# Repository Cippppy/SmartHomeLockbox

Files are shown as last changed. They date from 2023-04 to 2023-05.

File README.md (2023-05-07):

# Smart Home Lockbox
The Smart Home Lockbox is a project created by Christian Cipolletta and Matt Gerace for their final in Intro To Embedded Systems. It is a tool that will allow people to lock their important items. It utilizes Ultrasonic, temperature, CO2, humidity, pressure, and vibration sensors to be aware of external stimuli. The microcontroller, the MSP430FR2355, takes in those inputs and alerts the user to danger using buzzers, LEDs, and an internet webpage. A servo also locks the box if someone is detected.

## Power Supply
* Barrel Jack [For AC/DC Wall Plug]
* 2x 20mm Coin Cell Batteries + Holders
* 2x Linear Regulators, 1 for 5V, 1 for 3.3V

## Sensors
* BME280 Temperature, Humidity, Pressure Sensor Breakout Board [I2C]
* MQ-9B (Sen-17050) CO2 Sensor [Analog]
* MSP430FR2355 On Board Temperature Sensor [Analog]
* HC-SR04 Ultrasonic Sensor [Digital]
* MPU6050 Accelerometer and Gyroscope [I2C]

## Output Peripherals
* Red LED
* Blue LED
* Active Buzzer
* ESP01 Wifi Module [[ThingSpeak]](https://thingspeak.com/channels/2104523)
* Servo

## Where is the project at? (5/7/2023)
The onboard temperature sensor and ultrasonic sensors are confirmed to be working. The CO2 gives an ouput, but we do not know if it is correct. The batteries are not strong enough to run the circuit, so it is wall power right now. The I2C code doesn't work so the BME280 and MPU6050 aren't working now either. The servos, LEDs, buzzers, and ESP01 all work. The 3D printed box that will be the actual one that locks was successfully printed and locked by the servo. However, it was unable to be covered because it is too small to fit the full PCB at this time. You can read more on our [project slides](https://docs.google.com/presentation/d/1oNxZCWa-71zp4ZQAXbW0OE4L5BJcd05L6jm5VQH0Wrw/edit?usp=sharing) or our [project report](https://docs.google.com/document/d/1pnApUV6Cqu8zDdYJzm2F5OI0f5RzCBrWJ35Rd4LK8bY/edit?usp=sharing).

## Future Work
The next steps to take to make the project a full success start with remaking the PCB. First, the ESP01 needs to switch its trace. Second, the servo header needs to be retraced as well. Last, there needs to be a new battery choosen to the power the device. On the software side, the main fix is making sure the I2C connections are fixed. Once that is fixed, to make this device low-power it would be a benefit to make the code interrupt based instead of the current polling based system. The final thing to fix would be to make the lock box big enough to encase the PCB and all parts while still being able to be locked and to store items.

## Project Video
https://user-images.githubusercontent.com/98924381/235829279-1a4e9000-3827-43de-8596-dcd38e9c36f0.mp4

# Appendix
## Resources & Datasheets
* BME280 [Datasheet](https://cdn-learn.adafruit.com/downloads/pdf/adafruit-bme280-humidity-barometric-pressure-temperature-sensor-breakout.pdf), [Arduino Github](https://github.com/adafruit/Adafruit_BME280_Library)
* MPU6050 [Datasheet](https://www.haoyuelectronics.com/Attachment/GY-521/mpu6050.pdf)
* Ultrasonic [Datasheet](https://cdn.sparkfun.com/datasheets/Sensors/Proximity/HCSR04.pdf)
* MQ-9B [Datasheet](https://cdn.sparkfun.com/assets/d/f/5/e/2/MQ-9B_Ver1.4__-_Manual.pdf), [Wiring Example](http://wiring.org.co/learning/basics/airqualitymq135.html)
* Servo [Datasheet](http://www.ee.ic.ac.uk/pcheung/teaching/DE1_EE/stores/sg90_datasheet.pdf)
* ESP01 [Datasheet](https://www.universal-solder.ca/downloads/esp8266_series_modules_user_manual_en.pdf)
* Updating 3D Model of the Lockbox [OnShape](https://cad.onshape.com/documents/b93b4b42872b4098d45294de/w/dbbdbcc2a9ef1ffa882faf1d/e/f71d34ea460787590961a1fb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)

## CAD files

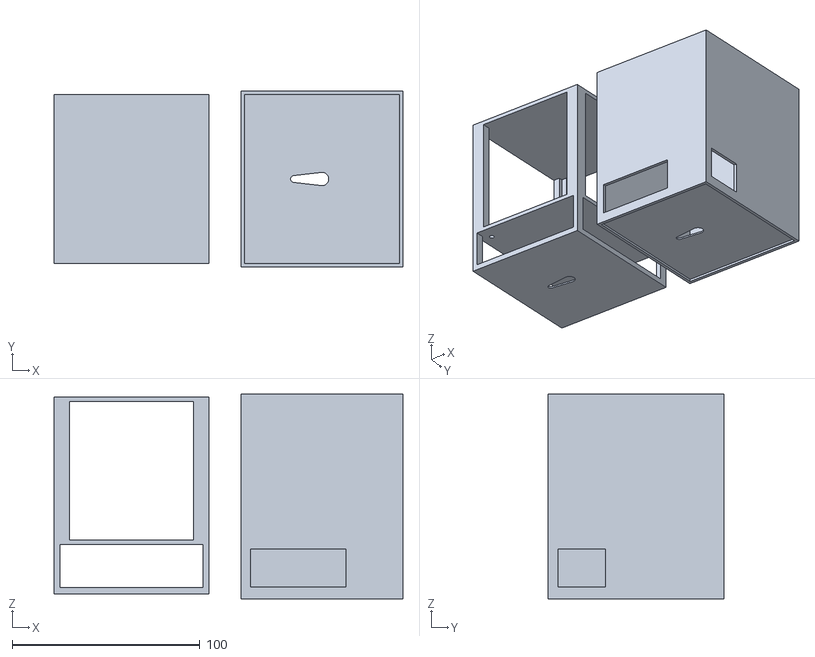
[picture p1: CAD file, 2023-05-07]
Lockbox_Model.stl
186.1 x 94.0 x 109.2

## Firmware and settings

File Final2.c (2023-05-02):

#include <msp430.h>
#include <stdint.h>
#include <stdbool.h>
#include "Drivers/GPIO_Driver.h"
#include "Drivers/FR2355_UART_Driver.h"
#include <Drivers/Adafruit_BME280.h>

/**
 * Final2.c
 */

// Variable Instantiation
char Vibration_Data_In;
float Temperature_Data_In;
float Humidity_Data_In;
float Pressure_Data_In;
volatile float CO2_Reading;
unsigned int position;

//on board temperature definitions
volatile float IntDegF;
#define CALADC_15V_30C  *((unsigned int *)0x1A1A)
#define CALADC_15V_85C  *((unsigned int *)0x1A1C)

//ADC mode definitions
#define CO2 1
#define OBTEMP 0
volatile unsigned char modeADC = 0x00;

// Text that prints to terminal if distance < 15
char alertText[] = {'D','A','N','G','E','R', ' ','N','E','A','R'};

// Text that prints to terminal when uart connects
char connectedText[] = {'S','u','c','c','e','s','s','f','u','l','l','y',' ','C','o','n','n','e','c','t','e','d'};

volatile unsigned long distance = 20;    // Holds distance calculated by ultrasonic sensor
volatile unsigned int pulseCount = 0;   // Holds count used to calculate distance

// Peripheral Instantiation
void Init_HCSR04();
void Init_Buzzer();
void Init_Servo();
void Init_LED();
void Init_WIFI();
void Init_TEMP();
void Init_CO2();
void Init_UART_Pins();
void Run_Ultrasonic();
// Method Instantiation
void readOBTemp();
void Init_ADC();
void readCO2();
void updateThingSpeak();
//void Run_Temp();
void Ultrasonic_Wait(unsigned int timeToWait);
void setServo(unsigned int angle);


void main(void)
{
    WDTCTL = WDTPW | WDTHOLD;                 // Stop WDT
    distance = 20;
    Init_HCSR04();
    Init_Buzzer();
    Init_Servo();
    Init_LED();
    Init_WIFI();
    Init_TEMP();
    Init_CO2();
    Init_ADC();
    Init_UART_Pins();

    // Disable the GPIO power-on default high-impedance mode to activate
    // previously configured port settings
    PM5CTL0 &= ~LOCKLPM5;

    __bis_SR_register(LPM0_bits + LPM3_bits + GIE); // Enter LPM0 and LPM3
    __enable_interrupt();   // Enables interrupts
    __no_operation();       // For debugger

    while(1)
    {
        Run_Ultrasonic();
        readOBTemp();
        while((ADCIFG & ADCIFG)==0);
        readCO2();
//        Run_Temp();
//        Temperature_Data_In = readTemperature();
//        Humidity_Data_In = readHumidity();
//        Pressure_Data_In = readPressure();
        if(distance < 15) { // If distance is less than 15 (maybe cm?)
            setServo(180);
            gpioWrite(3,2,1);   // Turn on Red LED
            gpioWrite(3,3,1);   // Turn on Blue LED
            gpioWrite(3,7,1);   // Turn on Buzzer
        }
        else {  // If distance is further than 15
            setServo(0);
            gpioWrite(3,2,0);   // Turn off Red LED
            gpioWrite(3,3,0);   // Turn off Blue LED
            gpioWrite(3,7,0);   // Turn off buzzer
        }
        updateThingSpeak();
        Ultrasonic_Wait(65000); // Wait some time (Maybe 65000 ms)
    }
}


/**
 * Peripheral Setups
 */

// Sets up ADC for On-Board Temp sensor and CO2 sensor
void Init_ADC()
{
    ADCCTL0 |= ADCSHT_8 | ADCON;                                  // ADC ON,temperature sample period>30us
    ADCCTL1 |= ADCSHP;                                            // s/w trig, single ch/conv, MODOSC
    ADCCTL2 &= ~ADCRES;                                           // clear ADCRES in ADCCTL
    ADCCTL2 |= ADCRES_2;                                          // 12-bit conversion results
    ADCMCTL0 |= ADCSREF_1 | ADCINCH_12;                           // ADC input ch A12 => temp sense
    ADCIE |=ADCIE0;                                               // Enable the Interrupt request for a completed ADC_B conversion
    modeADC = OBTEMP;

    PMMCTL0_H = PMMPW_H;                                          // Unlock the PMM registers
    PMMCTL2 |= INTREFEN | TSENSOREN;                              // Enable internal reference and temperature sensor
    __delay_cycles(400);                                          // Delay for reference settling
}

// Setting up pins for Computer terminal connection
void Init_UART_Pins()
{
    P4DIR = 0xFF; P2DIR = 0xFF;
    P4REN = 0xFF; P2REN = 0xFF;
    P4OUT = 0x00; P2OUT = 0x00;
    // Configure UART pins
    P4SEL0 |= BIT2 | BIT3;                    // set 2-UART pin as second function
}


// Setup Ultrasonic sensor to Pins 5.1 and 5.0 and Timer B2
void Init_HCSR04()
{
    gpioInit(5,1,1); // Set Pin 5.1 to OUTPUT (TRIG)
    gpioWrite(5,1,0); // Set Pin 5.1 to LOW

    gpioInit(5,0,0); // Set Pin 5.0 to INPUT (ECHO)
    P5SEL0 |= BIT0;
    P5SEL1 &= ~BIT0;

    // Configure Timer_B2
    TB2CCR0 = 50;   // Set to 50 because anything lower is too fast
    TB2CCTL0 = CCIE;    // TB2CCR0 interrupt enabled
    TB2CTL = TBSSEL__SMCLK | MC_2 | TBCLR;    // SMCLK, continuous mode, clear TBR
}

// Setup Buzzer to Pin 3.7
void Init_Buzzer()
{
    gpioInit(3,7,1); // Set Pin 3.7 to OUTPUT (Transistor Base)
    gpioWrite(3,7,0); // Set Pin 3.7 to LOW
}

// Setup Servo to Pin 6.0 and Timer B3
void Init_Servo()
{
    gpioInit(6,0,1); // Set Pin 6.0 to OUTPUT (Servo PWM)
    P6SEL0 |= BIT0;
    P6SEL1 &= ~BIT0; // P6.0 options select

    // Configure Timer_B3 for PWM
    TB3CCR0 = 39000;                         // PWM Period of 50Hz
    TB3CCTL1 = OUTMOD_7;                      // CCR1 reset/set
    TB3CCR1 = 39000*0.075;                   // CCR1 PWM duty cycle
    TB3CTL = TBSSEL__SMCLK | MC__UP | TBCLR | ID_2;  // SMCLK, up mode, clear TBR, Divide clock by 4
}

// Setup LEDs to Pin 3.2 and 3.3
void Init_LED()
{
    gpioInit(3,2,1); // Set Pin 3.2 to OUTPUT (RED LED)
    gpioWrite(3,2,0); // Set Pin 3.2 to LOW

    gpioInit(3,3,1); // Set Pin 3.3 to OUTPUT (BLUE LED)
    gpioWrite(3,3,0); // Set Pin 3.3 to LOW
}

// Setup Wifi Module
void Init_WIFI()
{
    UCA0CTLW0 |= UCSWRST; // Set USCI_A0 into software reset

    UCA0CTLW0 |= UCSSEL__ACLK; // Choose BRCLK=ACLK=32.768kHz
    UCA0BRW = 3; // Prescaler
    UCA0MCTLW |= 0X9200;    // Modulation

    // Tx Pin Setup
    P1SEL0 |= BIT7;
    P1SEL1 &= ~BIT7;

    UCA0CTLW0 &= ~UCSWRST; // Take USCI_A0 out of software reset
    UCA0IE |= UCRXIE;
}

// Setup Temperature Sensor to I2C Pins 1.6 and 1.7
void Init_TEMP()
{
    UCB1CTLW0 |= UCSWRST; // Set USCI_B1 into software reset

    UCB1CTLW0 |= UCSSEL_3; // Choose BRCLK=SMCLK=1MHz
    UCB1BRW = 10; // Divide BRCLK by 10 for SCL = 100kHz
    // Put into I2C mode, Put into Master mode, Synchronous mode
    UCB1CTLW0 |= UCMODE_3 | UCMST | UCSYNC | UCTR;
    // Slave addr is 7 bits, single master
    UCB1CTLW0 &= ~UCMM & ~UCSLA10;
    UCB1I2CSA = BME280_ADDRESS; // Slave address = 0x77 or 0x76
    UCB1CTLW1 |= UCASTP_2; // Auto STOP when UCB0TBCNT reached
    UCB1TBCNT = 20; // Send 1 byte of data

    // SCL Pin Setup
    P4SEL0 |= BIT7;
    P4SEL1 &= ~BIT7;

    // SDA Pin Setup
    P4SEL0 |= BIT6;
    P4SEL1 &= ~BIT6;

    UCB1CTLW0 &= ~UCSWRST; // Take USCI_B1 out of software reset

    UCB1IE |= UCTXIE; // Enable I2C Tx0 IRQ (writing interrupt)
    UCB1IE |= UCRXIE | UCNACKIE | UCBCNTIE; // Enable I2C Rx0 IRQ (receiving interrupt)
}

// Setup Vibration sensor to I2C Pins 1.2 and 1.3
void Init_Vibration()
{
    UCB0CTLW0 |= UCSWRST; // Set USCI_B0 into software reset

    UCB0CTLW0 |= UCSSEL_3; // Choose BRCLK=SMCLK=1MHz
    UCB0BRW = 10; // Divide BRCLK by 10 for SCL = 100kHz
    UCB0CTLW0 |= UCMODE_3 | UCMST; // Put into I2C mode, Put into Master mode
    UCB0I2CSA = 0x0068; // Slave address = 0x68
    UCB0CTLW1 |= UCASTP_2; //Auto STOP when UCB0TBCNT reached
    UCB0TBCNT = 0x01; // Send 1 byte of data

    // SCL Pin Setup
    P1SEL0 |= BIT3;
    P1SEL1 &= ~BIT3;

    // SDA Pin Setup
    P1SEL0 |= BIT2;
    P1SEL1 &= ~BIT2;

    UCB0CTLW0 &= ~UCSWRST; // Take USCI_B0 out of software reset

    UCB0IE |= UCTXIE0; // Enable I2C Tx0 IRQ (writing interrupt)
    UCB0IE |= UCRXIE0; // Enable I2C Rx0 IRQ (receiving interrupt)
}

// Setup CO2 Sensor to Pin 1.1 and ADC
void Init_CO2()
{
    gpioInit(1,1,0); // Set Pin 1.1 to INPUT (C02 Sensor)
}


/**
 * Peripheral Functions
 */

void Run_Ultrasonic()
{
    TB2CCR0 = 50;
    pulseCount = 0;
    unsigned int countLow = 0x00;   // Set count of LOW part of echo pulse to 0
    unsigned int countHigh = 0x00;  // Set count of HIGH part of echo pulse to 0
    gpioWrite(5,1,0);   // Set Trig pin LOW
    __delay_cycles(2);  // Delay 5 microseconds
    gpioWrite(5,1,1);   // Set Trig pin HIGH
    __delay_cycles(10); // Delay 10 microseconds
    gpioWrite(5,1,0);   // Set Trig Pin LOW
    while(gpioRead(5,0) == 0);
    countLow = pulseCount * 5;   // Set count of LOW part of echo pulse to pulseCount times 5 because of TB2CCR0 offset
    while(gpioRead(5,0) == 1);
    countHigh = pulseCount * 5;  // Set count of HIGH part of echo pulse to pulseCount times 5 because of TB2CCR0 offset
    unsigned int pulseWidth = countHigh - countLow; // Pulse width = total count - count of LOW part
    distance = (unsigned long) pulseWidth / 58.0;   // Conversion to cm according to datasheet
}

// Will be used to set servo angle
void setServo(unsigned int angle)
{
    if(angle >= 180) {
        TB3CCR1 = 39000 * 0.125;
    }
    else if(angle <= 0) {
        TB3CCR1 = 39000 * 0.03;
    }
    else {
        TB3CCR1 = 20.6 * angle + 1170;
    }
}

// Used to make the ultrasonic wait without using delay
void Ultrasonic_Wait(unsigned int timeToWait)
{
    unsigned int timeWaited = pulseCount;
    while((pulseCount - timeWaited) <= timeToWait);
}

//void Run_Temp() {
////    __delay_cycles(2000);
////    while (UCB1CTLW1 & UCTXSTP);         // Ensure stop condition got sent
////    UCB1CTL1 |= UCTXSTT;
//    UCB1CTLW0 |= UCTR;
//    UCB1CTLW0 |= UCTXSTT;
//    while ((UCB1IFG & UCSTPIFG) == 0);
//    UCB1CTLW0 &= ~UCTR;
//    UCB1CTLW0 |= UCTXSTT;
//    while ((UCB1IFG & UCSTPIFG) == 0);
//    UCB0IFG &= ~UCSTPIFG;
//}

// Read the CO2 sensor (A0)
void readCO2()
{
    modeADC = CO2;
    ADCMCTL0 |= ADCINCH_1;
    ADCCTL0 |= ADCENC | ADCSC;                                    // Sampling and conversion start
}

// Read the onboard Temperature sensor
void readOBTemp()
{
    modeADC = OBTEMP;
    ADCMCTL0 |= ADCINCH_12;
    ADCCTL0 |= ADCENC | ADCSC;                                    // Sampling and conversion start
}

void updateThingSpeak()
{
    int intOBT = (int) IntDegF;
    int intCO2 = (int) CO2_Reading;
    int intBME280 = (int) Temperature_Data_In;
    char message[13];
    message[0] = (intOBT / 100) + '0';
    message[1] = ((intOBT / 10) % 10) + '0';
    message[2] = (intOBT % 10) + '0';
    message[3] = ';';
    message[4] = (intCO2 / 1000) + '0';
    message[5] = ((intCO2 / 100) % 10) + '0';
    message[6] = ((intCO2 / 10) % 10) + '0';
    message[7] = (intCO2 % 10) + '0';
    message[8] = ':';
    message[9] = (intBME280 / 100) + '0';
    message[10] = ((intBME280 / 10) % 10) + '0';
    message[11] = (intBME280 % 10) + '0';
    message[12] = '.';
    //uart_Print(message);
    while((UCA0IFG & UCTXIFG)==0);
    UCA0TXBUF = message[0];
    while((UCA0IFG & UCTXIFG)==0);
    UCA0TXBUF = message[1];
    while((UCA0IFG & UCTXIFG)==0);
    UCA0TXBUF = message[2];
    while((UCA0IFG & UCTXIFG)==0);
    UCA0TXBUF = message[3];
    while((UCA0IFG & UCTXIFG)==0);
    UCA0TXBUF = message[4];
    while((UCA0IFG & UCTXIFG)==0);
    UCA0TXBUF = message[5];
    while((UCA0IFG & UCTXIFG)==0);
    UCA0TXBUF = message[6];
    while((UCA0IFG & UCTXIFG)==0);
    UCA0TXBUF = message[7];
    while((UCA0IFG & UCTXIFG)==0);
    UCA0TXBUF = message[8];
    while((UCA0IFG & UCTXIFG)==0);
    UCA0TXBUF = message[9];
    while((UCA0IFG & UCTXIFG)==0);
    UCA0TXBUF = message[10];
    while((UCA0IFG & UCTXIFG)==0);
    UCA0TXBUF = message[11];
    while((UCA0IFG & UCTXIFG)==0);
    UCA0TXBUF = message[12];
}

/**
 * Interrupt Routines
 */

// Interrupt routine for Vibration sensor
#pragma vector=EUSCI_B0_VECTOR
__interrupt void EUSCI_B0_I2C_ISR(void)
{
    switch(UCB0IV) // Which IRQ flag triggered
    {
    case 0x16 : // RXIFG0
        Vibration_Data_In = UCB0RXBUF; // Runs when Rx buffer has received data from the slave.
        break;
    case 0x18 : // TXIFG0
        UCB0TXBUF = 0xBB; // Runs when Tx buffer is ready to receive data from master.
        break;
    default :
        break;
    }
}

// Interrupt routine for Temperature sensor
#if defined(__TI_COMPILER_VERSION__) || defined(__IAR_SYSTEMS_ICC__)
#pragma vector = USCI_B1_VECTOR
__interrupt void USCIB1_ISR(void)
#elif defined(__GNUC__)
void __attribute__ ((interrupt(USCI_B1_VECTOR))) USCIB1_ISR (void)
#else
#error Compiler not supported!
#endif
{
    switch(UCB1IV) {
    case USCI_I2C_UCNACKIFG :
        UCB1CTL1 |= UCTXSTT;
        break;
    case 0x16 :
        Temperature_Data_In = UCB1RXBUF;
        break;
    case 0x18 :
        UCB1TXBUF = BME280_REGISTER_TEMPDATA;
        break;
    default :
        break;
    }
}

// Timer B2 interrupt service routine (For counting how long echo is high)
#pragma vector = TIMER2_B0_VECTOR
__interrupt void Timer2_B0_ISR(void)
{
    pulseCount++;
    TB2CCR0 += 50;               // Add Offset to TB0CCR0 (anything smaller than 50 is too fast)
}

// ADC interrupt service routine
#if defined(__TI_COMPILER_VERSION__) || defined(__IAR_SYSTEMS_ICC__)
#pragma vector=ADC_VECTOR
__interrupt void ADC_ISR(void)
#elif defined(__GNUC__)
void __attribute__ ((interrupt(ADC_VECTOR))) ADC_ISR (void)
#else
#error Compiler not supported!
#endif
{
    volatile float temp;

    volatile float IntDegC;

    switch(__even_in_range(ADCIV,ADCIV_ADCIFG))
    {
        case ADCIV_NONE:
            break;
        case ADCIV_ADCOVIFG:
            break;
        case ADCIV_ADCTOVIFG:
            break;
        case ADCIV_ADCHIIFG:
            break;
        case ADCIV_ADCLOIFG:
            break;
        case ADCIV_ADCINIFG:
            break;
        case ADCIV_ADCIFG:
            if(modeADC) {
                CO2_Reading = ADCMEM0;
            }
            else {
                temp = ADCMEM0;
                // Temperature in Celsius
                // The temperature (Temp, C)=
                IntDegC = (temp-CALADC_15V_30C)*(85-30)/(CALADC_15V_85C-CALADC_15V_30C)+30;

                // Temperature in Fahrenheit
                // Tf = (9/5)*Tc | 32
                IntDegF = 9*IntDegC/5+32;
                //__bic_SR_register_on_exit(LPM3_bits);               // Exit LPM3
            }
            break;
        default:
            break;
    }
}

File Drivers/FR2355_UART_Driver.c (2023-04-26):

/*
 * FR2355_UART.c
 *
 *  Created on: Dec 7, 2022
 *      Author: traffo17
 */

#include <msp430.h>
#include "FR2355_UART_Driver.h"


/**
 * UART Init for 9600 Baud
 */

void uart_Init_9600(){
    PM5CTL0 &= ~LOCKLPM5;                    // Disable the GPIO power-on default high-impedance mode
                                              // to activate 1previously configured port settings

     __bis_SR_register(SCG0);                 // disable FLL
     CSCTL3 |= SELREF__REFOCLK;               // Set REFO as FLL reference source
     CSCTL1 = DCOFTRIMEN_1 | DCOFTRIM0 | DCOFTRIM1 | DCORSEL_3;// DCOFTRIM=3, DCO Range = 8MHz
     CSCTL2 = FLLD_0 + 243;                  // DCODIV = 8MHz
     __delay_cycles(3);
     __bic_SR_register(SCG0);                // enable FLL
     Software_Trim();                        // Software Trim to get the best DCOFTRIM value

     CSCTL4 = SELMS__DCOCLKDIV | SELA__REFOCLK; // set default REFO(~32768Hz) as ACLK source, ACLK = 32768Hz
                                              // default DCODIV as MCLK and SMCLK source



     // Configure UART
     UCA1CTLW0 |= UCSWRST;
     UCA1CTLW0 |= UCSSEL__SMCLK;

     // Baud Rate calculation
     // 8000000/(16*9600) = 52.083
     // Fractional portion = 0.083
     // User's Guide Table 17-4: UCBRSx = 0x49
     // UCBRFx = int ( (52.083-52)*16) = 1
     UCA1BR0 = 52;                             // 8000000/16/9600
     UCA1BR1 = 0x00;
     UCA1MCTLW = 0x4900 | UCOS16 | UCBRF_1;

     UCA1CTLW0 &= ~UCSWRST;                    // Initialize eUSCI
     UCA1IE |= UCRXIE;                         // Enable USCI_A0 RX interrupt

}

/**
 * UART Software Trim
 * Used to trim the oscillator within the USCI peripheral to match the exact clock.
 */

void Software_Trim()
{
    unsigned int oldDcoTap = 0xffff;
    unsigned int newDcoTap = 0xffff;
    unsigned int newDcoDelta = 0xffff;
    unsigned int bestDcoDelta = 0xffff;
    unsigned int csCtl0Copy = 0;
    unsigned int csCtl1Copy = 0;
    unsigned int csCtl0Read = 0;
    unsigned int csCtl1Read = 0;
    unsigned int dcoFreqTrim = 3;
    unsigned char endLoop = 0;

    do
    {
        CSCTL0 = 0x100;                         // DCO Tap = 256
        do
        {
            CSCTL7 &= ~DCOFFG;                  // Clear DCO fault flag
        }while (CSCTL7 & DCOFFG);               // Test DCO fault flag

        __delay_cycles((unsigned int)3000 * MCLK_FREQ_MHZ);// Wait FLL lock status (FLLUNLOCK) to be stable
                                                           // Suggest to wait 24 cycles of divided FLL reference clock
        while((CSCTL7 & (FLLUNLOCK0 | FLLUNLOCK1)) && ((CSCTL7 & DCOFFG) == 0));

        csCtl0Read = CSCTL0;                   // Read CSCTL0
        csCtl1Read = CSCTL1;                   // Read CSCTL1

        oldDcoTap = newDcoTap;                 // Record DCOTAP value of last time
        newDcoTap = csCtl0Read & 0x01ff;       // Get DCOTAP value of this time
        dcoFreqTrim = (csCtl1Read & 0x0070)>>4;// Get DCOFTRIM value

        if(newDcoTap < 256)                    // DCOTAP < 256
        {
            newDcoDelta = 256 - newDcoTap;     // Delta value between DCPTAP and 256
            if((oldDcoTap != 0xffff) && (oldDcoTap >= 256)) // DCOTAP cross 256
                endLoop = 1;                   // Stop while loop
            else
            {
                dcoFreqTrim--;
                CSCTL1 = (csCtl1Read & (~DCOFTRIM)) | (dcoFreqTrim<<4);
            }
        }
        else                                   // DCOTAP >= 256
        {
            newDcoDelta = newDcoTap - 256;     // Delta value between DCPTAP and 256
            if(oldDcoTap < 256)                // DCOTAP cross 256
                endLoop = 1;                   // Stop while loop
            else
            {
                dcoFreqTrim++;
                CSCTL1 = (csCtl1Read & (~DCOFTRIM)) | (dcoFreqTrim<<4);
            }
        }

        if(newDcoDelta < bestDcoDelta)         // Record DCOTAP closest to 256
        {
            csCtl0Copy = csCtl0Read;
            csCtl1Copy = csCtl1Read;
            bestDcoDelta = newDcoDelta;
        }

    } while(endLoop == 0);                      // Poll until endLoop == 1

    CSCTL0 = csCtl0Copy;                       // Reload locked DCOTAP
    CSCTL1 = csCtl1Copy;                       // Reload locked DCOFTRIM
    while(CSCTL7 & (FLLUNLOCK0 | FLLUNLOCK1)); // Poll until FLL is locked
}




/** uart_Print(char *InputString)
 * Sends a STRING over UART using polling. Note that the input is a pointer to a character array which is NULL terminated
 * Input: pointer to char array with NULL termination.
 *
 * Requires uart_Init_9600 to be run prior to using this function.
 */
void uart_Print(char *InputString){
    while(*InputString != 0) {
        while (!(UCA1IFG&UCTXIFG));
        UCA1TXBUF = *InputString++;
    }
    while (!(UCA1IFG&UCTXIFG));
    UCA1TXBUF = 0x0A;
    while (!(UCA1IFG&UCTXIFG));
    UCA1TXBUF = 0x0D;
}

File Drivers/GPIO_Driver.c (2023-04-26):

/*
 * GPIO_Driver.c
 *
 *  Created on: Jan 28, 2023
 *      Author: Christian Cipolletta
 */



#include "GPIO_Driver.h"
#include <msp430.h>


/**
 * gpioInit(char Port, char Pin, char Direction)
 * Used to configure a single GPIO pin as an input or output.
 *
 * char Port: takes values from 1-6
 * char Pin: takes values from 0-7
 * char Direction: 0 for Input, 1 for Output
 *
 * Example: Setting pin 1.0 to an output
 * gpioInit(1, 0, 1);
 */

void gpioInit(char Port, char Pin, char Direction){

   unsigned char PinNumber = 0x01 << Pin;       // Creates PinNumber which represents the
                                                // BIT that needs to be flipped based on the selected Pin

   if(Direction) {                              // If the Direction is Output (1)

       switch(Port) {                           // Case statement that sets the correct PxOUT to 0
                                                // and PxDIR to 1 based on which Port is choosen

       case 1 :
           P1OUT &= ~PinNumber;
           P1DIR |= PinNumber;
           break;
       case 2 :
           P2OUT &= ~PinNumber;
           P2DIR |= PinNumber;
           break;
       case 3 :
           P3OUT &= ~PinNumber;
           P3DIR |= PinNumber;
           break;
       case 4 :
           P4OUT &= ~PinNumber;
           P4DIR |= PinNumber;
           break;
       case 5 :
           P5OUT &= ~PinNumber;
           P5DIR |= PinNumber;
           break;
       case 6 :
           P6OUT &= ~PinNumber;
           P6DIR |= PinNumber;
           break;

       }
   }

   else {                                    // If Direction is Input (0)

       switch(Port) {                       // Case statement that sets the correct
                                            // PxREN to high, PxOUT to high, and PxDIR to low

       case 1 :
           P1REN |= PinNumber;
           P1DIR &= ~PinNumber;
           P1OUT |= PinNumber;
           break;
       case 2 :
           P2REN |= PinNumber;
           P2DIR &= ~PinNumber;
           P2OUT |= PinNumber;
           break;
       case 3 :
           P3REN |= PinNumber;
           P3DIR &= ~PinNumber;
           P3OUT |= PinNumber;
           break;
       case 4 :
           P4REN |= PinNumber;
           P4DIR &= ~PinNumber;
           P4OUT |= PinNumber;
           break;
       case 5 :
           P5REN |= PinNumber;
           P5DIR &= ~PinNumber;
           P5OUT |= PinNumber;
           break;
       case 6 :
           P6REN |= PinNumber;
           P6DIR &= ~PinNumber;
           P6OUT |= PinNumber;
           break;

       }
   }
}



/**
 * gpioWrite(char Port, char Pin, char Value)
 * Used to write a 1 or 0 to a Pin which has already been declared as an output.
 *
 * char Port: takes values from 1-6
 * char Pin: takes values from 0-7
 * char Value: 0 or 1
 *
 * Example: Setting pin 1.0 to a 1
 * gpioWrite(1, 0, 1);
 */

void gpioWrite(char Port, char Pin, char Value){

    char PinNumber = 0x01 << Pin;

    if(Value) {                         // If the Value is 1

        switch(Port) {                  // Case statement that sets PxOUT to high
                                        // depending on the Port

        case 1 :
            P1OUT |= PinNumber;
            break;
        case 2 :
            P2OUT |= PinNumber;
            break;
        case 3 :
            P3OUT |= PinNumber;
            break;
        case 4 :
            P4OUT |= PinNumber;
            break;
        case 5 :
            P5OUT |= PinNumber;
            break;
        case 6 :
            P6OUT |= PinNumber;
            break;

        }
    }

    else {                              // If the Value is 0

        switch(Port) {                  // Case statement that sets PxOUT to low

        case 1 :
            P1OUT &= ~PinNumber;
            break;
        case 2 :
            P2OUT &= ~PinNumber;
            break;
        case 3 :
            P3OUT &= ~PinNumber;
            break;
        case 4 :
            P4OUT &= ~PinNumber;
            break;
        case 5 :
            P5OUT &= ~PinNumber;
            break;
        case 6 :
            P6OUT &= ~PinNumber;
            break;

        }
    }
}


/**
 * gpioRead(char Port, char Pin)
 * Used to Read from a pin which has been declared as an input.
 * Returns a 1 or 0 based on pin value.
 *
 * char Port: takes values from 1-6
 * char Pin: takes values from 0-7
 *
 * Example: Reading Pin 1.1
 * unsigned char PinState = gpioRead(1, 1);
 */

char gpioRead(char Port, char Pin){

    char Value;                         // Creates a char that will be returned

    char PinNumber = 0x01 << Pin;

    switch(Port) {                      // Case statement that sets Value to whatever
                                        // PxIN is depending on the Port

    case 1 :
        Value = P1IN & PinNumber;
        break;
    case 2 :
        Value = P2IN & PinNumber;
        break;
    case 3 :
        Value = P3IN & PinNumber;
        break;
    case 4 :
        Value = P4IN & PinNumber;
        break;
    case 5 :
        Value = P5IN & PinNumber;
        break;
    case 6 :
        Value = P6IN & PinNumber;
        break;

    }

    return Value;

}

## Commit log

2023-04-26 updated final code with on board temperature
2023-05-04 Created Drivers Folder
